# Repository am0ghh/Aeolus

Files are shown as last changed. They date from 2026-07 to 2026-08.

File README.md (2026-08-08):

# Aeolus

**Aeolus** is a smart, temperature-aware IR fan controller built around an ESP32-C3. It watches room temperature and automatically turns a WOOZOO (or other NEC-protocol) fan on and off over infrared, with a 0.96" OLED status display, a physical control button, and an on-device IR "learn" mode for capturing new remote codes — all on a custom-designed 4-layer PCB.

Named after Aeolus, the keeper of the winds.

## Gallery

**3D render**

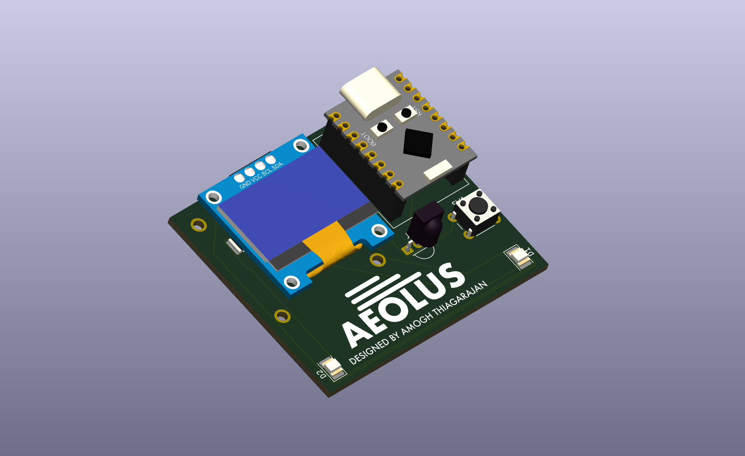
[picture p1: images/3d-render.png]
Aeolus 3D render


**PCB layout** (4-layer, black soldermask, silkscreen branding)

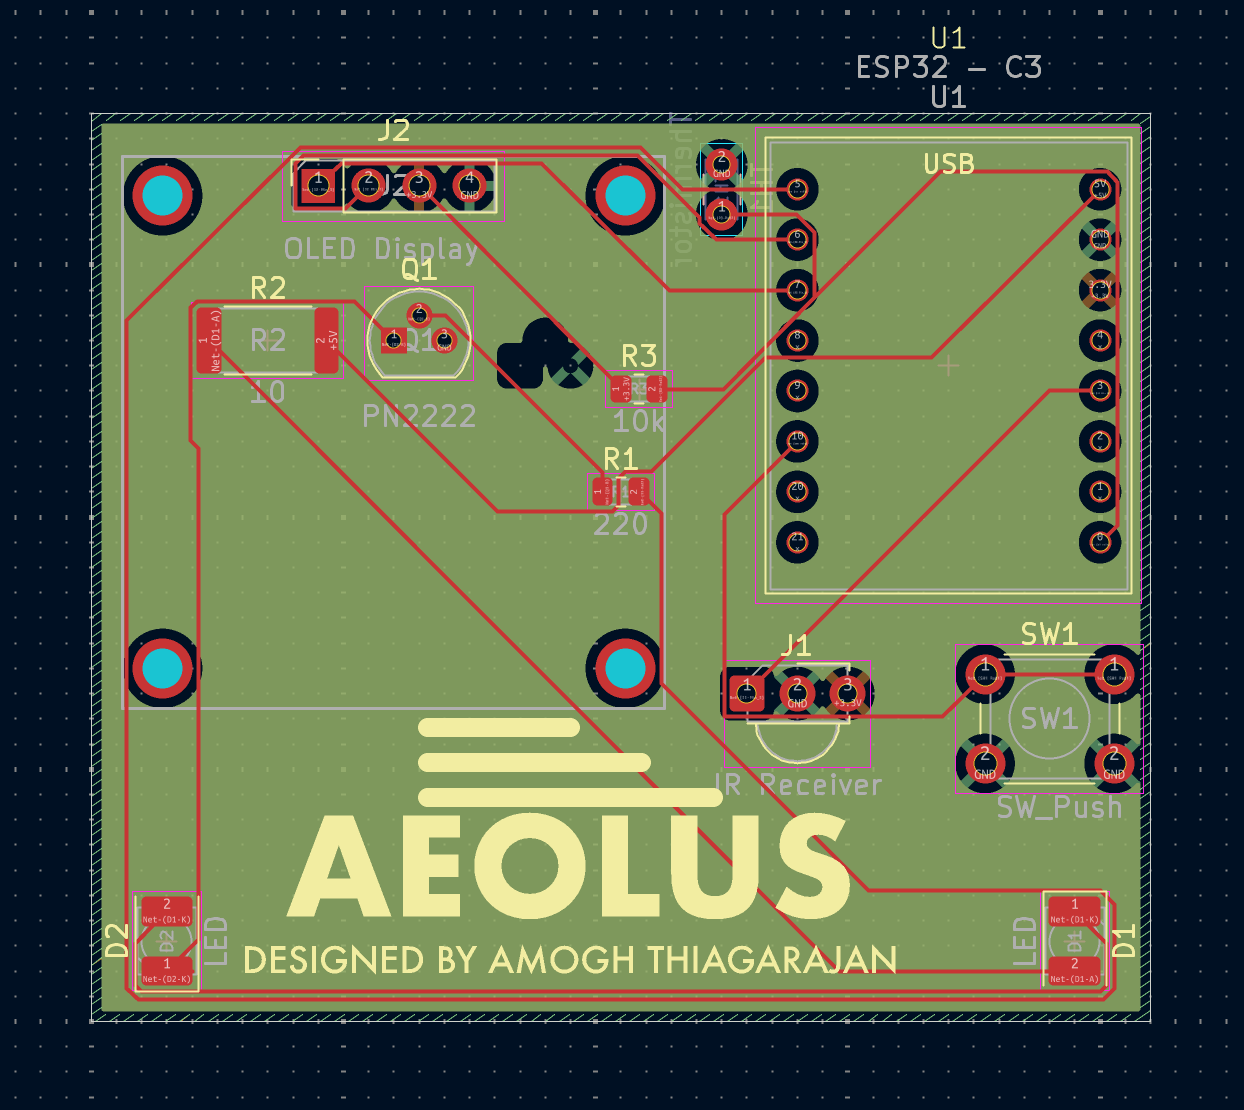
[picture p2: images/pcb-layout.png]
Aeolus PCB layout


**Schematic**

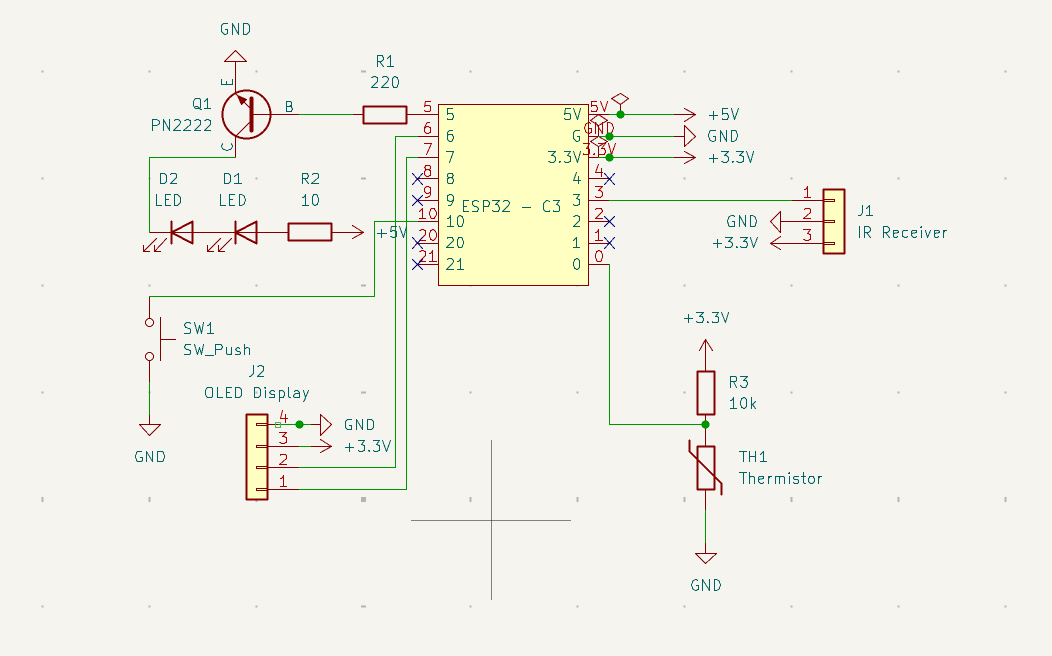
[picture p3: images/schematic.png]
Aeolus schematic


## Background — this is v2 of my [fans](https://github.com/am0ghh/fans) project

Aeolus is a ground-up redesign of my earlier [dorm-room fan automation project](https://github.com/am0ghh/fans). The original ("fans") was an Arduino Uno R3 on a breadboard: a DHT11 sensor, an IR receiver, and a transistor-driven IR LED that automatically toggled the fan on hysteresis. It worked, but it was bulky, code-only, and limited to hardcoded remote codes.

Aeolus keeps the proven control logic and rebuilds everything around it as a real, compact, hardware product.

### Design improvements over v1 (`fans`)

| Area | v1 — `fans` | v2 — Aeolus |
|---|---|---|
| **Microcontroller** | Arduino Uno R3 (ATmega328P, 5V, large) | ESP32-C3 SuperMini (32-bit RISC-V, 3.3V, tiny, Wi-Fi/BLE capable) |
| **Temperature sensing** | DHT11 module (slow, ~1 Hz, NaN dropouts) | NTC thermistor read on the ADC with a Beta-equation conversion — faster, cheaper, no library timing quirks |
| **Display** | None (serial monitor only) | 0.96" SSD1306 I²C OLED with live temp/state readout and wind/snow animations |
| **User input** | None | Physical push button — single/double-tap for mode and manual control |
| **Remote codes** | Hardcoded in firmware | On-device IR **learn/scan mode** — capture a new remote's code without reflashing |
| **Build** | Breadboard / protoboard prototype | Custom 4-layer PCB designed in KiCad (SIG–GND–PWR–SIG stackup), black soldermask, silkscreen branding |
| **Form factor** | Loose modules and jumper wires | Single integrated board with the OLED and modules socketed |

The transistor-buffered IR transmitter (the key range fix from v1 — extends usable range from a couple of inches to ~10–15 ft) is carried over into the Aeolus hardware.

## Hardware

- **ESP32-C3 SuperMini** microcontroller module
- **0.96" SSD1306 OLED** (I²C, address `0x3C`)
- **NTC thermistor** on the ADC for temperature sensing
- **IR receiver** (38 kHz demodulating, VS1838B-style) for learning remote codes
- **IR LED (940 nm)** transmitter, transistor-buffered for range
- **Momentary push button** for manual control / mode switching
- Custom 4-layer KiCad PCB (`hardware/Aeolus.kicad_pcb` / `.kicad_sch`)

### Pin map

| Function | ESP32-C3 GPIO |
|---|---|
| IR transmit | GPIO5 |
| IR receive | GPIO3 |
| OLED SDA | GPIO7 |
| OLED SCL | GPIO6 |
| Button | GPIO10 |
| Thermistor (ADC) | GPIO0 |

## Firmware

The firmware lives in [`src/main.cpp`](src/main.cpp) and is built with PlatformIO (Arduino framework for ESP32-C3).

- **Automatic control with hysteresis** — fan turns on at 75 °F, off at 73 °F, so it won't rapidly cycle around the setpoint.
- **Minimum run time** — once the fan starts, it stays on for at least 10 minutes.
- **Two operating modes** — a normal run/monitor mode and a scan (IR-learn) mode, toggled from the button.
- **IR learn mode** — point your fan remote at the receiver and Aeolus captures the raw NEC code so it can replay it later.
- **OLED UI** — shows current temperature and fan state with animated wind (fan on) and snow (idle/cool) effects.
- Sends NEC-protocol IR commands (default is the WOOZOO fan power code).

### Build & flash

This is a [PlatformIO](https://platformio.org/) project:

```bash
pio run              # build
pio run -t upload    # flash to the ESP32-C3
pio device monitor   # serial output
```

Board and framework are configured in [`platformio.ini`](platformio.ini). Libraries used: IRremote, Adafruit SSD1306, Adafruit GFX.

## PCB & hardware design

The KiCad 9 project is in [`hardware/`](hardware/) (schematic, PCB, custom symbol/footprint libraries). Highlights:

- **4-layer board** — SIG–GND–PWR–SIG. `In1.Cu` carries a poured GND plane and `In2.Cu` a poured +3.3V plane. Every ground and supply pad is through-hole, so the plated barrels tie straight into the planes with thermal reliefs and no stitching vias are needed. That is why there is not a single GND trace on `F.Cu` — the plane carries every return, which keeps the loop area of the switched IR LED current away from the high-impedance thermistor sense line.
- **Custom ESP32-C3 SuperMini symbol and footprint**, pin-labeled to match the actual module.
- **Custom silkscreen branding** (the "Aeolus" wordmark) generated from the artwork in [`branding/`](branding/).
- 3D models for the ESP32-C3, OLED, and IR components in `hardware/Aeolus.3dshapes/` for a complete 3D render.

## Known limitations

Stated up front so the files and the description agree:

- **Signal routing is single-sided.** All 75 copper segments sit on `F.Cu`; `B.Cu` is unused for routing. This is fine at this node count because power and ground are handled by the inner planes rather than by surface traces.
- **No decoupling capacitors are placed.** `schematic-guide.txt` calls for 100 nF on the OLED and IR receiver supplies; those parts are not yet in the schematic.
- **No I²C pull-ups on the board** — the design relies on the ones fitted to the OLED breakout.
- **The board has not been fabricated.** Everything in `hardware/` is layout and 3D render only; no gerbers, BOM, or assembled unit yet.
- **The IR range figures are estimates**, not instrumented measurements.

## License

See [LICENSE](LICENSE).

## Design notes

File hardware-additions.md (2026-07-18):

# Hardware additions — IR booster, light sensing, temp sensing

Planning notes for three hardware additions to Aeolus (ESP32-C3). No firmware
changes yet — wiring only. Code will be added once hardware is in place.

## 1. PN2222 IR booster (low-side switch + LED bank)

`IrSender.begin(IR_SEND_PIN)` currently drives GPIO5 straight into an IR LED,
capped at the GPIO's own current limit (~20mA safe / 40mA abs max) — that's
the range bottleneck. The transistor moves LED current off the GPIO entirely;
the GPIO just switches the transistor's base.

Power source: **5V available** (USB VBUS pin on the devkit).

### Wiring (low-side NPN switch)

Two separate current loops meet at the transistor — easiest to read as a
connection list rather than a box diagram:

| From | Connects to |
|---|---|
| 5V rail | Resistor R1 (10Ω) — pin 1 |
| R1 — pin 2 | LED1 anode (+, longer leg) |
| LED1 cathode (−) | LED2 anode (+) |
| LED2 cathode (−) | PN2222 **Collector** |
| PN2222 **Emitter** | GND (same ground as the ESP32) |
| GPIO5 | Resistor R2 (220Ω) — pin 1 |
| R2 — pin 2 | PN2222 **Base** |

As a single-line trace of each path:

```
Power path (high current, ~200mA):
  5V ──[R1 10Ω]──▶ LED1(+ ──▶ −) ──▶ LED2(+ ──▶ −) ──▶ [Collector]

Control path (low current, ~12mA):
  GPIO5 ──[R2 220Ω]──▶ [Base]

Return path (shared):
  [Emitter] ──▶ GND
```

`[Collector]`, `[Base]`, `[Emitter]` are the three legs of the same PN2222 —
the transistor is the single point where all three lines join. Nothing else
on the board ties Collector, Base, and Emitter together directly.

- **LED config:** 2x IR LEDs **in series**, one shared 10Ω resistor. At 5V
  this leaves ~2.2V across the resistor after 2×Vf (~1.3V each) + transistor
  Vce_sat (~0.2V), giving ~200mA through both LEDs — current is automatically
  balanced in series, no per-LED resistor needed. (3 in series at 5V leaves
  too little headroom and gets sensitive to Vf tolerance — stick with 2.)
- **Base resistor:** 220Ω from GPIO5 gives ~12mA base current — plenty to
  hard-saturate a PN2222 at 200mA collector current (forced gain ~17x), while
  staying well under GPIO limits. IR bursts are brief/low-duty, so sustained
  GPIO heating isn't a concern.
- **Resistor power rating:** use ½W even though average dissipation is tiny
  (low duty cycle) — cheap insurance against a stuck/looping send.
- **Scaling further:** if 2 LEDs isn't enough range, add a second series-pair
  branch (own 10Ω resistor) off the same 5V rail and the same collector node —
  two independent 2-LED strings in parallel, each self-balanced, combined
  ~400mA. Still within PN2222's 600mA abs max collector rating but closer to
  the edge — try the single string first.
- **Why not reuse the existing 100Ω resistor:** the 100Ω currently in the
  circuit was sized for the *old* direct-GPIO-drive setup — GPIO5 (3.3V) →
  100Ω → LED → GND gives `(3.3 - 1.3Vf) / 100Ω ≈ 20mA`, the safe ceiling for a
  GPIO. Once the transistor is driving the LEDs from 5V instead, 100Ω only
  gives `(5 - 2.6Vf - 0.2Vce) / 100Ω ≈ 22mA` — almost no improvement, since
  it defeats the point of bypassing the GPIO's current limit. Dropping to
  10Ω at 5V gives ~220mA. If a 10Ω isn't on hand, equal resistors in
  parallel work as a stand-in (R/n for n resistors): 4× 100Ω in parallel ≈
  25Ω (~88mA) is a reasonable stopgap; 10× 100Ω in parallel ≈ 10Ω (~220mA)
  matches the target exactly but is impractical to build. A real 10–22Ω
  resistor is cheap and worth sourcing directly.
- **Pinout warning:** PN2222 TO-92 pinout (E-B-C) varies by
  manufacturer/clone. Verify with a multimeter diode-test or datasheet before
  wiring — reversing E/C won't always destroy it but will misbehave, and
  reversing B can pull current straight from GPIO into the LED rail.

This is a pure wiring change — `IrSender.begin(5)` keeps working unmodified
since GPIO5 still just outputs the same logic-level carrier signal.

## 2. Photoresistor (LDR) → OLED brightness

Free up an ADC pin (avoid GPIO2/8/9, the strapping pins). ESP32-C3 ADC1
channels: GPIO0/1/2/3/4. GPIO3 is taken by `IR_RECEIVE_PIN`, so use **GPIO4**
for the LDR.

### Voltage divider

```
3.3V ── LDR ──┬── GPIO4 (ADC1_CH4)
              │
           [10kΩ] ── GND
```

With the LDR on top: bright room → LDR resistance drops → more voltage at the
ADC node (higher reading in light, lower in dark — intuitive mapping). 10kΩ
fixed resistor is a reasonable starting point since most common LDRs (e.g.
GL5528) sit around 10kΩ under normal indoor lighting — gives good ADC swing
across the room's actual light range. Measure the specific LDR's resistance
in the room (lights on vs off) with a multimeter; tune the fixed resistor
toward that value if the ADC range ends up too compressed.

No extra hardware needed for the brightness side — the SSD1306 has a
software contrast register (0–255), so once there's an analog reading,
dimming is just an I2C command (`display.dim()` or a direct contrast write).
That part lands in code later.

## 3. Thermistor (NTC) → temperature trigger

Replaces the old `fans` project's DHT11. Use another free ADC1 pin, e.g.
**GPIO0** or **GPIO1**.

### Voltage divider

```
3.3V ── [Rfixed] ──┬── GPIO0 (ADC1_CH0)
                    │
                 Thermistor ── GND
```

Match `Rfixed` to the thermistor's nominal 25°C resistance (commonly 10kΩ for
generic breadboard NTCs marked "MF52" — these typically use β≈3950).
Conversion later uses the Beta equation against the divider-derived
resistance.

**Before wiring, confirm (or measure) on the actual thermistor:**
- Its nominal resistance at 25°C (often printed/marked, e.g. "103" = 10kΩ)
- Its Beta/B-coefficient (datasheet value; 3950 is the common default for
  generic 10k NTCs if unmarked)

If neither is findable, a multimeter resistance reading at a known room
temperature is enough to back-calculate a usable Beta later.

## Pin map after all three additions

| Function | Pin | Notes |
|---|---|---|
| IR TX (to transistor base) | GPIO5 | unchanged |
| IR RX | GPIO3 | unchanged |
| OLED SDA / SCL | GPIO7 / GPIO6 | unchanged |
| LDR (light) | GPIO4 | ADC1_CH4 |
| Thermistor | GPIO0 | ADC1_CH0 |
| *(spare ADC)* | GPIO1 | ADC1_CH1, free for later |

## Next step

Once wired up, add to `main.cpp`:
- ADC reads for LDR + thermistor
- Brightness mapping (LDR reading → SSD1306 contrast)
- Temperature-trigger logic (carrying over the hysteresis + minimum-runtime
  pattern from the `fans` project)

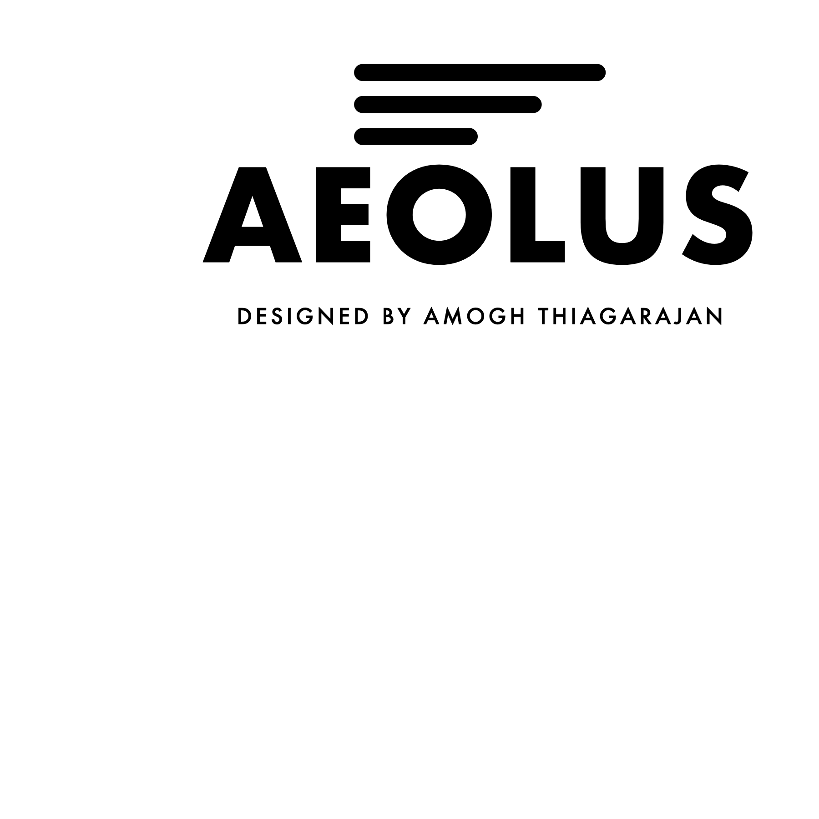
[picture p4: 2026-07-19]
branding/aeolus-silk.png

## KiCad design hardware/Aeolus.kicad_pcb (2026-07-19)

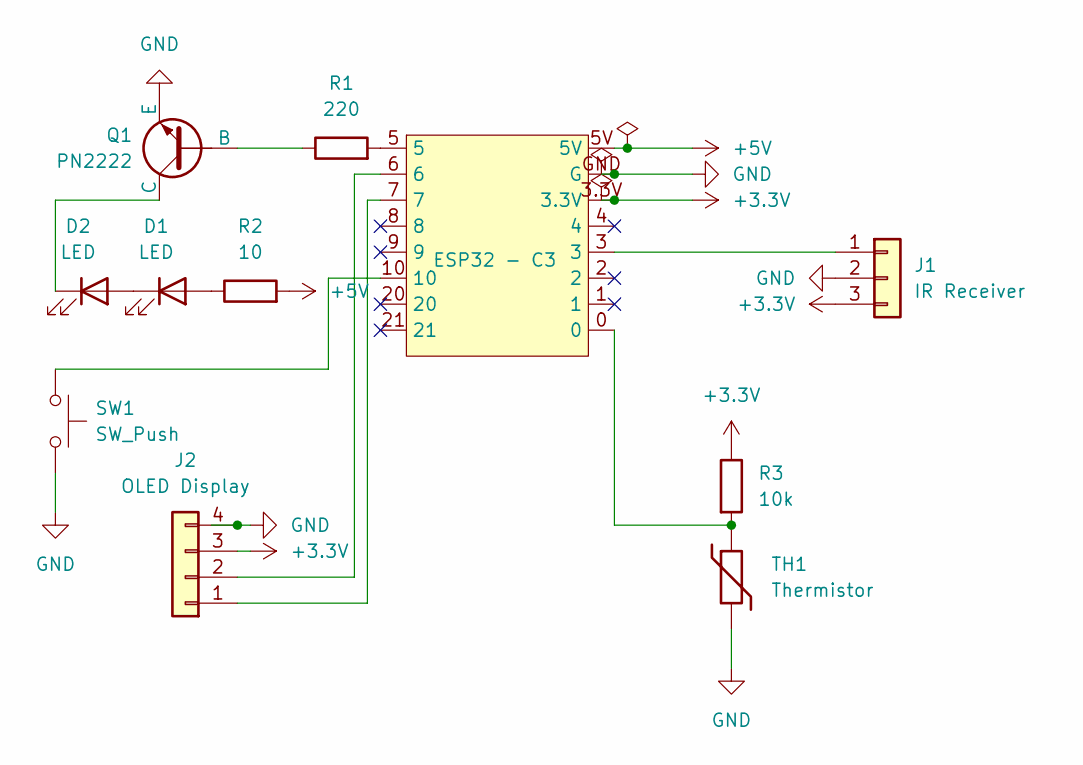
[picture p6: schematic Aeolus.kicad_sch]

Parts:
D1, D2: LED; LED_PLCC-2_3.4x3.0mm_KA
J1: IR Receiver; Vishay_MINICAST-3Pin
J2: OLED Display; OLED_SSD1306_I2C_0.96
Q1: PN2222; TO-92
R1: 220; R_0805_2012Metric
R2: 10; R_2512_6332Metric
R3: 10k; R_0805_2012Metric
SW1: SW_Push; SW_PUSH_6mm
TH1: Thermistor; C_Disc_D3.0mm_W1.6mm_P2.50mm
U1: ESP32 - C3; ESP32-C3-SuperMini

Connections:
+3.3V: J1.3, J2.3, R3.1, U1.3.3V
+5V: R2.2, U1.5V
GND: J1.2, J2.4, Q1.3 (E), SW1.2, TH1.2, U1.GND (G)
unnamed: D1.2 (A), R2.1
unnamed: D1.1 (K), D2.2 (A)
unnamed: D2.1 (K), Q1.1 (C)
unnamed: J1.1, U1.3
unnamed: J2.1, U1.7
unnamed: J2.2, U1.6
unnamed: Q1.2 (B), R1.1
unnamed: R1.2, U1.5
unnamed: R3.2, TH1.1, U1.0
unnamed: SW1.1, U1.10

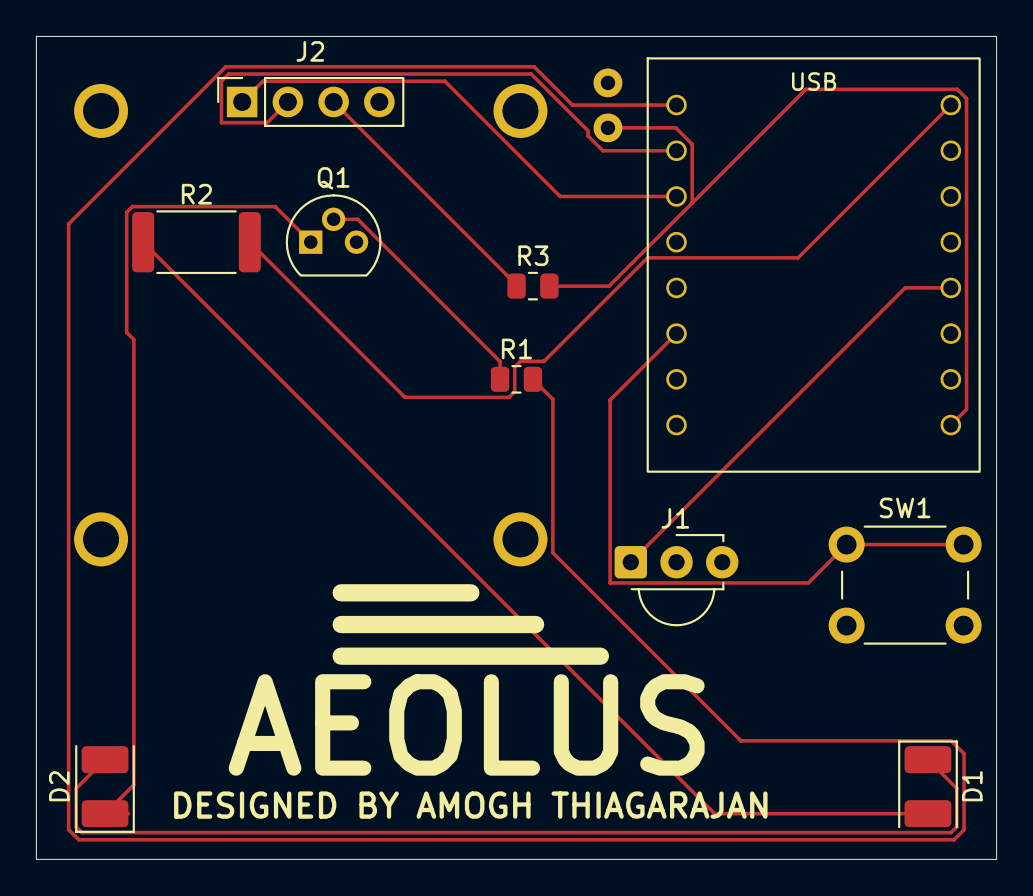
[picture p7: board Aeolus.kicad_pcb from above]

Board: 4 copper layers, 53.3 x 45.7 mm, 11 parts (1 on the bottom side), 13 nets.

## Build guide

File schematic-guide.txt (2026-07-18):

aAEOLUS — KICAD SCHEMATIC GUIDE
================================
ESP32-C3 smart fan controller: IR TX booster, IR RX, OLED, LDR, thermistor.
You already have the custom ESP32-C3 symbol. Place that first, then wire
everything below to its GPIO labels.

Use net labels (Place → Net Label) to keep wires clean instead of long rats-nest
lines. You'll want at minimum: +3V3, +5V, GND, SDA, SCL, IR_TX, IR_RX, THERM_ADC, BTN.

────────────────────────────────────────────────────────────────
1. POWER RAILS
────────────────────────────────────────────────────────────────
The DevKit's onboard LDO gives you +3V3 from USB. USB VBUS gives +5V.
Expose both as power symbols so every sub-circuit can reference them.

  Symbol: PWR → VCC (label it +3V3)
  Symbol: PWR → VCC (label it +5V)
  Symbol: PWR → GND

Place a 100nF decoupling cap (C_Small) from +3V3 to GND near the OLED
connector, and another near the IR RX module. Small but good practice.

────────────────────────────────────────────────────────────────
2. IR TX BOOSTER  (GPIO5 → PN2222 → 2× IR LEDs)
────────────────────────────────────────────────────────────────
Symbols needed:
  Q_NPN_BCE  (or search "Q_NPN" — use BCE pin order matching PN2222 TO-92)
  R (×2)
  LED (×2, use LED_Infrared if available, or plain LED)

Connections:
  GPIO5  ──[R2 220Ω]──▶ Base  (Q1 PN2222)
  Emitter (Q1)         ──▶ GND

  +5V    ──[R1 10Ω]──▶ D1 Anode (+)
  D1 Cathode (−)       ──▶ D2 Anode (+)
  D2 Cathode (−)       ──▶ Collector (Q1)

Values to fill in:
  R1 = 10Ω  ½W
  R2 = 220Ω  ¼W
  D1, D2 = IR LED (940nm, e.g. TSAL6400 or whatever you have)
  Q1 = PN2222A  (double-check your part's pinout — E-B-C order varies by maker)

Net label on Q1 Base node: IR_TX  → tie to ESP32 GPIO5 pin via same label.

Annotation note: some KiCad NPN symbols have pins labeled C/B/E; others use
1/2/3. Map Collector=C, Base=B, Emitter=E regardless of the number.

────────────────────────────────────────────────────────────────
3. IR RECEIVER  (GPIO3)
────────────────────────────────────────────────────────────────
Symbol: a generic 3-pin connector (Conn_01x03) is fine if you don't have the
exact module symbol. Label the pins:
  Pin 1 = VCC  → +3V3
  Pin 2 = GND  → GND
  Pin 3 = OUT  → IR_RX net label (ties to GPIO3)

Common module footprint: VS1838B or TSOP38238 (38 kHz demodulator).
Add a 100nF cap from the module's VCC to GND right at those pins.

────────────────────────────────────────────────────────────────
4. SSD1306 OLED  (I2C, GPIO7=SDA, GPIO6=SCL, address 0x3C)
────────────────────────────────────────────────────────────────
Symbol: a 4-pin connector (Conn_01x04) or look up Adafruit_SSD1306 in KiCad
community libraries.

Pins:
  GND   → GND
  VCC   → +3V3
  SCL   → SCL net label (ties to GPIO6)
  SDA   → SDA net label (ties to GPIO7)

Pull-up resistors (I2C requires these if not already on the module PCB —
most Adafruit/clone breakouts include them, so skip if yours does):
  4.7kΩ from SDA to +3V3
  4.7kΩ from SCL to +3V3

Wire.setClock(400000) is set in firmware (fast mode) — these pull-up values
are fine for that speed at short trace lengths.

────────────────────────────────────────────────────────────────
5. THERMISTOR (NTC)  (GPIO0 = ADC1_CH0)
────────────────────────────────────────────────────────────────
Voltage divider: fixed resistor on top, NTC on bottom.
As temperature rises → NTC resistance drops → ADC voltage rises.

  +3V3 ──[R4 10kΩ]──┬── THERM_ADC net label (ties to GPIO0)
                      │
                   [NTC thermistor]
                      │
                     GND

Symbols:
  R (R4, 10kΩ — this is Rfixed / THERM_SERIES_R in the firmware)
  R_Thermistor (or Thermistor_NTC if in your KiCad library)

Firmware defaults: nominal R = 10kΩ at 25°C, Beta = 3950.
If your specific part has different values, you can update THERM_BETA and
THERM_NOMINAL_R in main.cpp later.

────────────────────────────────────────────────────────────────
6. BUTTON  (GPIO10)
────────────────────────────────────────────────────────────────
Single press = toggle device active/inactive.
Double tap (two presses within 300ms) = enter 10-second scan mode.
Firmware enables the internal pull-up, so the line sits at 3.3V when open
and is pulled to GND when pressed — no external pull-up resistor needed.

Symbol: SW_Push  (Device library)

Connections:
  Pin 1 (A) → BTN net label (ties to GPIO10)
  Pin 2 (B) → GND

Optional: 100nF cap from Pin 1 to GND in parallel with the button.
This is hardware debounce on top of the software debounce already in
firmware — cheap insurance against noisy contacts, especially on a PCB.

Net label on Pin 1: BTN  → ties to ESP32 GPIO10 pin via same label.

────────────────────────────────────────────────────────────────
7. ESP32-C3 PIN ASSIGNMENTS (your custom symbol)
────────────────────────────────────────────────────────────────
Connect net labels on the ESP32-C3 symbol to match these:

  GPIO0  →  THERM_ADC
  GPIO3  →  IR_RX
  GPIO5  →  IR_TX
  GPIO6  →  SCL
  GPIO7  →  SDA
  GPIO10 →  BTN
  GND    →  GND  (connect all GND pins)
  3V3    →  +3V3
  5V/VBUS→  +5V   (only needed if your symbol exposes the VBUS pin)

GPIO1 and GPIO4 are spare (ADC1_CH1/CH4), leave unconnected or add test points.
GPIO2/8/9 are strapping pins — leave unconnected unless you know what you're doing.

────────────────────────────────────────────────────────────────
8. QUICK CHECKLIST BEFORE YOU RUN ERC
────────────────────────────────────────────────────────────────
[ ] Every component has a Reference and Value filled in (R1, R2 ... Q1, D1, D2, SW1)
[ ] PWR_FLAG symbols on +3V3, +5V, and GND nets (ERC requires these)
[ ] All net labels spelled identically — a stray space causes a disconnected net
[ ] PN2222 pinout verified (E-B-C vs C-B-E depending on your symbol source)
[ ] I2C pull-ups: present if your OLED module doesn't have them onboard
[ ] Decoupling caps on OLED VCC and IR RX VCC
[ ] GPIO4 left unconnected (was LDR, now spare)
[ ] Button: one pin to BTN net, other to GND — no pull-up resistor (firmware uses internal)

────────────────────────────────────────────────────────────────
COMPONENT SUMMARY
────────────────────────────────────────────────────────────────
Ref   Value         Notes
----  -------       -----
U1    ESP32-C3      your custom symbol
Q1    PN2222A       NPN transistor, TO-92
D1    IR LED 940nm  series pair, no individual resistors needed
D2    IR LED 940nm
R1    10Ω  ½W       IR LED current limit (5V rail)
R2    220Ω ¼W       Q1 base resistor
R3    10kΩ ¼W       thermistor upper divider (Rfixed)
RT1   10kΩ NTC      thermistor, B=3950
J1    OLED SSD1306  4-pin I2C module
J2    IR RX module  3-pin (VCC/GND/OUT), e.g. VS1838B
SW1   SW_Push       tactile button, GPIO10; single press=on/off, double tap=scan mode
C5    100nF         optional, across SW1 pins for hardware debounce

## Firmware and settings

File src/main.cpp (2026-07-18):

#include <Arduino.h>
#include <Wire.h>
#include <Adafruit_GFX.h>
#include <Adafruit_SSD1306.h>
#include <IRremote.hpp>

#define IR_SEND_PIN    5
#define IR_RECEIVE_PIN 3
#define BUTTON_PIN     10

/* ─── OLED (SSD1306, I2C) ─────────────────────────────────────────── */
#define OLED_SDA   7
#define OLED_SCL   6
#define OLED_ADDR  0x3C
#define SCREEN_W   128
#define SCREEN_H   64

Adafruit_SSD1306 display(SCREEN_W, SCREEN_H, &Wire, -1);

/* ─── Thermistor (NTC, Beta equation) ─────────────────────────────────
 * Divider: 3.3V -> 10k -> THERM_PIN -> thermistor -> GND. */
#define THERM_PIN         0
#define ADC_MAX           4095.0f
#define THERM_NOMINAL_R   10000.0f
#define THERM_NOMINAL_T   25.0f
#define THERM_BETA        3950.0f
#define THERM_SERIES_R    10000.0f

#define TEMP_ON_F     75.0f
#define TEMP_OFF_F    73.0f
#define MIN_RUN_TIME  600000UL
#define TX_ANIM_MS    2500UL
#define CODE_GAP_MS   50UL

/* ─── Scan mode ────────────────────────────────────────────────────── */
#define SCAN_DURATION_MS  10000UL
#define MAX_LEARNED       8
#define CODE_FLASH_MS     600UL

#define WOOZOO_CODE  0xFF00DE80UL

static uint32_t learnedCodes[MAX_LEARNED];
static int      learnedCount   = 0;
static bool     scanMode       = false;
static uint32_t scanStart      = 0;
static uint32_t codeFlashUntil = 0;

/* ─── Normal-mode state ────────────────────────────────────────────── */
static bool     deviceActive  = true;   // single-tap toggles this
static uint32_t lastTempCheck = 0;
static bool     fanOn         = false;
static uint32_t fanOnTime     = 0;
static float    lastTempF     = 70.0f;
static uint32_t txAnimUntil   = 0;

/* ─── Button: debounce + single/double-tap detection ──────────────── */
#define DEBOUNCE_MS    50
#define DOUBLE_TAP_MS 300   // max gap between two presses to count as double-tap

static bool     btnStable     = HIGH;
static bool     btnLastRead   = HIGH;
static uint32_t btnDebounce   = 0;
static int      btnPressCount = 0;
static uint32_t btnFirstPress = 0;

enum BtnEvent { BTN_NONE, BTN_SINGLE, BTN_DOUBLE };

/* Returns BTN_DOUBLE immediately on the second press within DOUBLE_TAP_MS,
 * or BTN_SINGLE once the window expires with only one press. */
static BtnEvent checkButton() {
  bool reading = digitalRead(BUTTON_PIN);
  if (reading != btnLastRead) btnDebounce = millis();
  btnLastRead = reading;

  BtnEvent event = BTN_NONE;

  if ((millis() - btnDebounce) >= DEBOUNCE_MS && reading != btnStable) {
    btnStable = reading;
    if (btnStable == LOW) {                  // falling edge = press
      btnPressCount++;
      if (btnPressCount == 1) {
        btnFirstPress = millis();
      } else if (btnPressCount >= 2) {
        event = BTN_DOUBLE;
        btnPressCount = 0;
      }
    }
  }

  if (btnPressCount == 1 && (millis() - btnFirstPress) >= DOUBLE_TAP_MS) {
    event = BTN_SINGLE;
    btnPressCount = 0;
  }

  return event;
}

/* ─── Snow ─────────────────────────────────────────────────────────── */
#define N_SNOW 16
struct Snow { float x, y, speed, sway; uint8_t r; };
static Snow snow[N_SNOW];
static float lastFrame = 0;

/* ─── Drawing helpers ──────────────────────────────────────────────── */

static void drawWind(float t, int baseY, int amp, float k, float speed, int dash) {
  int prevX = 0;
  int prevY = baseY + (int)(amp * sinf(-speed * t));
  for (int x = 2; x <= SCREEN_W; x += 2) {
    int y = baseY + (int)(amp * sinf(k * x - speed * t));
    if (((x / 2) % dash) != 0)
      display.drawLine(prevX, prevY, x, y, SSD1306_WHITE);
    prevX = x;
    prevY = y;
  }
}

static void drawSnowflake(int x, int y, int r) {
  if (r <= 0) { display.drawPixel(x, y, SSD1306_WHITE); return; }
  display.drawFastHLine(x - r, y, 2 * r + 1, SSD1306_WHITE);
  display.drawFastVLine(x, y - r, 2 * r + 1, SSD1306_WHITE);
  int d = (r * 7) / 10;
  display.drawLine(x - d, y - d, x + d, y + d, SSD1306_WHITE);
  display.drawLine(x - d, y + d, x + d, y - d, SSD1306_WHITE);
}

static void drawChevron(int x, int y) {
  display.drawLine(x,     y - 3, x + 3, y, SSD1306_WHITE);
  display.drawLine(x + 3, y,     x,     y + 3, SSD1306_WHITE);
  display.drawLine(x + 3, y - 3, x + 6, y, SSD1306_WHITE);
  display.drawLine(x + 6, y,     x + 3, y + 3, SSD1306_WHITE);
}

static void drawBreezeGust(float t) {
  drawWind(t, 6,  9,  0.15f, 6.0f, 2);
  drawWind(t, 20, 10, 0.10f, 7.0f, 2);
  drawWind(t, 44, 10, 0.12f, 6.5f, 2);
  drawWind(t, 58, 9,  0.16f, 7.5f, 2);
  int sweepX = (int)fmodf(t * 60.0f, SCREEN_W + 24) - 24;
  drawChevron(sweepX,      SCREEN_H / 2);
  drawChevron(sweepX - 16, SCREEN_H / 2 - 12);
  drawChevron(sweepX - 16, SCREEN_H / 2 + 12);
}

static void drawScanMode() {
  uint32_t elapsed   = millis() - scanStart;
  uint32_t remaining = (elapsed < SCAN_DURATION_MS) ? (SCAN_DURATION_MS - elapsed) : 0;
  int secsLeft       = (int)((remaining + 999) / 1000);

  display.clearDisplay();

  // Blinking title
  if ((millis() / 400) % 2) {
    display.setTextSize(2);
    display.setTextColor(SSD1306_WHITE);
    display.setCursor(4, 2);
    display.print("SCAN MODE");
  }

  // Countdown in top-right corner
  display.setTextSize(2);
  display.setTextColor(SSD1306_WHITE);
  display.setCursor(SCREEN_W - 24, 2);
  display.print(secsLeft);

  // Code count
  display.setTextSize(1);
  display.setCursor(10, 24);
  display.print("Found: ");
  display.print(learnedCount);
  display.print(" / ");
  display.print(MAX_LEARNED);

  // Inverted flash banner when a new code is captured
  if (millis() < codeFlashUntil) {
    display.fillRect(0, 35, SCREEN_W, 12, SSD1306_WHITE);
    display.setTextColor(SSD1306_BLACK);
    display.setCursor(14, 38);
    display.print("CODE CAPTURED!");
    display.setTextColor(SSD1306_WHITE);
  }

  // Progress bar (fills left->right as time elapses)
  const int barX = 8, barY = 52, barW = SCREEN_W - 16, barH = 8;
  int filled = constrain((int)((float)elapsed / SCAN_DURATION_MS * barW), 0, barW);
  display.drawRect(barX, barY, barW, barH, SSD1306_WHITE);
  if (filled > 0) display.fillRect(barX, barY, filled, barH, SSD1306_WHITE);

  display.display();
}

/* ─── Thermistor ───────────────────────────────────────────────────── */
static float readThermistorF() {
  int adc      = analogRead(THERM_PIN);
  float rTherm = THERM_SERIES_R * adc / (ADC_MAX - adc);
  float invT   = logf(rTherm / THERM_NOMINAL_R) / THERM_BETA
                 + 1.0f / (THERM_NOMINAL_T + 273.15f);
  float tempC  = 1.0f / invT - 273.15f;
  return tempC * 9.0f / 5.0f + 32.0f;
}

/* ─── IR send ──────────────────────────────────────────────────────── */
/* Sends Woozoo first, then every learned code with a brief gap.
 * RX is off during normal operation, so no restartTimer() needed. */
static void sendPowerToggle() {
  Serial.println("Sending power signal...");
  IrSender.sendNECRaw(WOOZOO_CODE, 0);
  for (int i = 0; i < learnedCount; i++) {
    delay(CODE_GAP_MS);
    IrSender.sendNECRaw(learnedCodes[i], 0);
  }
  txAnimUntil = millis() + TX_ANIM_MS;
}

/* ─── Fan state machine ────────────────────────────────────────────── */
static void updateFanState(float tempF) {
  if (!fanOn && tempF >= TEMP_ON_F) {
    sendPowerToggle();
    fanOn     = true;
    fanOnTime = millis();
  } else if (fanOn && tempF <= TEMP_OFF_F && millis() - fanOnTime >= MIN_RUN_TIME) {
    sendPowerToggle();
    fanOn = false;
  }
}

/* ─── Scan mode entry / exit ───────────────────────────────────────── */
static void enterScanMode() {
  if (scanMode) return;
  scanMode  = true;
  scanStart = millis();
  IrReceiver.start();
  Serial.println("Scan mode: started");
}

static void exitScanMode() {
  scanMode = false;
  IrReceiver.stop();
  Serial.print("Scan mode: ended, learned=");
  Serial.println(learnedCount);
}

/* ═══════════════════════════════════════════════════════════════════ */
void setup() {
  Serial.begin(115200);

  pinMode(BUTTON_PIN, INPUT_PULLUP);

  IrSender.begin(IR_SEND_PIN);
  IrReceiver.begin(IR_RECEIVE_PIN, DISABLE_LED_FEEDBACK);
  IrReceiver.stop();   // RX stays off until scan mode is triggered

  Wire.begin(OLED_SDA, OLED_SCL);
  Wire.setClock(400000);
  if (!display.begin(SSD1306_SWITCHCAPVCC, OLED_ADDR, true, false)) {
    Serial.println("SSD1306 not found");
  }
  display.setTextWrap(false);

  randomSeed(micros());
  for (int i = 0; i < N_SNOW; i++) {
    snow[i].x     = random(SCREEN_W);
    snow[i].y     = random(SCREEN_H);
    snow[i].speed = 7 + random(18);
    snow[i].sway  = random(628) / 100.0f;
    snow[i].r     = random(3);
  }

  Serial.println("Ready");
}

void loop() {
  // ── Button events ──
  switch (checkButton()) {
    case BTN_SINGLE:
      deviceActive = !deviceActive;
      Serial.println(deviceActive ? "Active" : "Inactive");
      break;
    case BTN_DOUBLE:
      enterScanMode();
      break;
    default: break;
  }

  /* ── Scan mode: owns the display for its duration ── */
  if (scanMode) {
    if (IrReceiver.decode()) {
      uint32_t code = IrReceiver.decodedIRData.decodedRawData;
      IrReceiver.resume();
      if (code != 0 && code != WOOZOO_CODE) {
        bool known = false;
        for (int i = 0; i < learnedCount; i++)
          if (learnedCodes[i] == code) { known = true; break; }
        if (!known && learnedCount < MAX_LEARNED) {
          learnedCodes[learnedCount++] = code;
          codeFlashUntil = millis() + CODE_FLASH_MS;
          Serial.print("Learned: 0x");
          Serial.println(code, HEX);
        }
      }
    }
    if (millis() - scanStart >= SCAN_DURATION_MS) exitScanMode();
    else drawScanMode();
    return;
  }

  /* ── Normal mode ── */

  // Temperature check and fan control only when active
  if (deviceActive && millis() - lastTempCheck >= 5000) {
    lastTempF = readThermistorF();
    Serial.print("Temp: "); Serial.print(lastTempF); Serial.println("F");
    updateFanState(lastTempF);
    lastTempCheck = millis();
  }

  // Animation frame
  float t  = millis() / 1000.0f;
  float dt = t - lastFrame;
  lastFrame = t;
  display.clearDisplay();

  if (millis() < txAnimUntil) {
    drawBreezeGust(t);
  } else {
    drawWind(t, 10, 5, 0.11f, 3.0f, 4);
    drawWind(t, 32, 7, 0.08f, 2.2f, 3);
    drawWind(t, 54, 6, 0.13f, 3.6f, 5);
  }

  for (int i = 0; i < N_SNOW; i++) {
    snow[i].y += snow[i].speed * dt;
    if (snow[i].y > SCREEN_H + 2) {
      snow[i].y = -2;
      snow[i].x = random(SCREEN_W);
    }
    int sx = (int)(snow[i].x + 5.0f * sinf(t * 1.3f + snow[i].sway));
    drawSnowflake(sx, (int)snow[i].y, snow[i].r);
  }

  // Temperature readout badge (bobbing)
  const int bob = (int)(2.0f * sinf(t * 1.5f));
  const int bw  = 100, bh = 42;
  const int bx  = (SCREEN_W - bw) / 2;
  const int by  = (SCREEN_H - bh) / 2 + bob;

  display.fillRoundRect(bx, by, bw, bh, 6, SSD1306_BLACK);
  display.drawRoundRect(bx, by, bw, bh, 6, SSD1306_WHITE);
  if ((millis() / 350) % 2)
    display.drawRoundRect(bx + 3, by + 3, bw - 6, bh - 6, 4, SSD1306_WHITE);

  char tempStr[3];
  snprintf(tempStr, sizeof(tempStr), "%2d", (int)(lastTempF + 0.5f));
  const int numW = 6 * 3 * 2;
  const int numX = bx + (bw - numW) / 2;
  const int numY = by + 5;
  display.setTextSize(3);
  display.setTextColor(SSD1306_WHITE);
  display.setCursor(numX, numY);     display.print(tempStr);
  display.setCursor(numX + 1, numY); display.print(tempStr);

  // Sub-line: thresholds when active, INACTIVE label when paused
  display.setTextSize(1);
  if (deviceActive) {
    char threshStr[16];
    snprintf(threshStr, sizeof(threshStr), "ON:%d OFF:%d", (int)TEMP_ON_F, (int)TEMP_OFF_F);
    const int subW = strlen(threshStr) * 6;
    display.setCursor(bx + (bw - subW) / 2, by + bh - 11);
    display.print(threshStr);
  } else {
    const int subW = 8 * 6;   // "INACTIVE" = 8 chars
    display.setCursor(bx + (bw - subW) / 2, by + bh - 11);
    display.print("INACTIVE");
  }

  // Bottom bar
  display.fillRect(0, 56, SCREEN_W, 8, SSD1306_BLACK);
  display.setTextSize(1);
  display.setCursor(2, 56);
  display.print("fans:");
  display.print(learnedCount + 1);
  display.print(deviceActive ? " | dbl:scan" : " | PAUSED");

  display.display();
}

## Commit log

2026-07-18 Add ESP32-C3 smart fan controller firmware and hardware design
    Firmware (src/main.cpp): thermistor-driven IR fan control with
    hysteresis, OLED animated UI, button single/double-tap, and an
    IR-learning scan mode. Includes PlatformIO config, KiCad schematic/PCB,
    and hardware/schematic notes.
    [Aeolus.kicad_pcb, Untitled.kicad_pcb, Untitled.kicad_sch]
2026-07-19 Add KiCad hardware design, branding, and full README
    - Add Aeolus schematic, 4-layer PCB, custom footprints (ESP32-C3
    SuperMini, OLED, silkscreen logo) and 3D models
    - Fix IR LED 3D model references to a shipping KiCad model
    - Add branding artwork (logo/silk SVG + PNG)
    - Rewrite README: project overview, hardware, firmware, pin map,
    PCB notes, and design improvements over the v1 fans project
    - Remove leftover Untitled.* project files and gitignore KiCad
    backups/caches
    [Aeolus.kicad_pcb, Aeolus.kicad_sch, Untitled.kicad_pcb]
2026-07-19 Rename KiCad project folder Untitled -> hardware
    - Rename the folder holding the schematic, PCB, footprints, symbols
    and 3D models to a descriptive name
    - Fix stale 'Untitled' project-name refs inside the schematic
    - Update README paths to hardware/
    [Aeolus.kicad_pcb, Aeolus.kicad_sch]
2026-07-19 Add hardware images (3D render, PCB layout, schematic) and README gallery
2026-08-07 Correct stackup claim and document known limitations
    The 4-layer stackup is defined but unused: all 75 copper segments are on
    F.Cu, there are zero vias, and the GND/+3.3V inner zones are floating.
    Also notes the missing decoupling caps, the absent I2C pull-ups, that the
    board has not been fabricated, and that the IR range figures are estimates.
2026-08-07 Describe the board as 2-layer
    The 4-layer stackup was never used: all copper is on F.Cu, there are no
    vias, and the two inner planes were floating. Two layers is what the node
    count calls for anyway. Notes that KiCad Board Setup still declares 4 and
    that a ground pour on B.Cu is the outstanding hardware task.
2026-08-08 Restore 4-layer description: the inner planes are connected
    The board is a functioning SIG-GND-PWR-SIG design, not 2-layer. In1.Cu
    carries a poured GND plane and In2.Cu a poured +3.3V plane, both filled
    with thermal reliefs. Every ground and supply pad is through-hole on
    *.Cu, so the plated barrels connect straight into the planes - stitching
    vias are unnecessary, which is why zero vias does not mean the planes are
    floating. It is also why there is not a single GND trace on F.Cu: the
    plane carries every return.
    The earlier 'single-sided routing, ground on surface traces' limitation
    was backwards and has been corrected.
